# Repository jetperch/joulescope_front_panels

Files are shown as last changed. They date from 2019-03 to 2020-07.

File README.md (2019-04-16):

# Joulescope Front Panels

Welcome to Joulescope™ front panel hardware design project.  This project 
contains the open source hardware designs for a variety of Joulescope front
panels.  These front panels customize Joulescope so that it can more easily 
connect to your power supply and target device.
For more information on Joulescope, see 
[www.joulescope.com](https://www.joulescope.com).

As of Mar 2019, all designs were done in Autodesk Eagle PCB.

The [Baseline PDF](fp_baseline.pdf) show the board outline and critical 
dimensions.

The boards have been fabricated using PCBWay. 
Here are the order notes ([example](pcbway_order.png)):

* Size: 77.6 x 26.6 mm
* Solder Mask: Black
* Surface Finish: HASL lead free, yes to accept ENIG substitution
* Special requests: Place all markings (such as pcb order number) on back.  Add flammability rating marking, such as 94V-0.

## License

All Joulescope front-panel designs are released under the 
permissive Apache 2.0 license.

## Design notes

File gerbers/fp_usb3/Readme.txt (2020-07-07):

Project: JouleScope_USB3

Files are provided "AS IS" for reference only, 
WITHOUT WARRANTY OF ANY KIND, EXPRESS OR IMPLIED.  

Designed by: 
    Mikhail Volkov
    Mettler-Toledo AutoChem, Inc.

As of July 6, 2020, I authorize Jetperch LLC to add these files
to the joulescope_front_panel repository under either the 
Apache 2.0 license or the 
Creative Commons 4.0 Attribution (CC BY) license.

---

Number of copper layers: 4
Layer Stackup:
 L01_TOP - signal
 L02_PLN - gnd
 L03_PLN - 
 L04_PLN - power

Control the single-ended characteristic impedance (Z0) of USB signals to between 40 Ohm and 55 Ohm
Control the differential impedance (Zdiff) of the USB 2.0 DP/DM signals to 90 Ohm, +5/-10 Ohm
Control the differential impedance (Zdiff) of the USB 3.0 (3.1) SS_TX+/- and SS_RX+/- signals to 85 Ohm, +/-5 Ohm

UL:	YES	
Material Thickness:	.062
MatSpec:	NP-175  or equivalent
SMColor:	Black
IDColor (Silk Screen):	White
Finished Copper Weight:1 oz. inners - 1.5 oz. outers
Plating Finish:	Imm. Gold	
Number of copper layers: 4

Micro-vias: None
Buried vias: None, vias throughtout
Via in pad: No
PCB outline and cutouts on: Mechanic, TopPrint, BotPrint, DrillMap
Software used: WinQcad

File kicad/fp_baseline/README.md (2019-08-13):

# Kicad versions of Joulescope front panel 

This is a conversion from the pdf dimensioned drawing of the baseline Joulescope JS110 front panel.

## Main features

* All files were initially generated in Kicad Application Version: (5.1.0)-1, release build
* The board edge, SMD pads, pin3 via, screw holes, light pipe hole are implemented in a .kicad_mod footprint file
* The copper pours are implemented in the .kicad_pcb file, as they will need to be recalculated every time you add or move additional components
* There is a specific .lib kicad symbol included, which may make your schematics easier to read, as opposed to a generic 5 pin header

Initial conversion by @SimonMerrett 
Please submit all pull requests and issues to @mliberty1 but be aware that the Kicad files are a community contribution

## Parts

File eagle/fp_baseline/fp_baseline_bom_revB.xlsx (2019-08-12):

Baseline Front Panel BOM - Rev B
2019 Aug 12
# | Ref Des | Qty | Value | Package | Description | Mfg | Mfg Part # | Notes
1 | J1 | 1 |  | 0.1" 1x5 SM | Surface mount header | Samtec | TSM-105-01-S-SV
2 | H1 | 1 |  |  | Light pipe | Dialight | 51513020125F
3 | PCB | 1 |  |  | PCB

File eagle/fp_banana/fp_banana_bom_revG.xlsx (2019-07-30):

Banana Jack Front Panel BOM - Rev G
2019 June 10
# | Ref Des | Qty | Value | Package | Description | Mfg | Mfg Part # | Notes
1 | J1, J3 | 2 |  |  | Safety banana jack - black | Cal Test | CT3149-0
2 | J2, J4 | 2 |  |  | Safety banana jack - red | Cal Test | CT3149-2
3 | J5 | 1 |  | 0.1" 1x5 SM | Surface mount header | Samtec | TSM-105-01-S-SV
4 | H1 | 1 |  |  | Light pipe | Dialight | 51513020125F
5 |  | 1 |  |  | PCB | PCBWay | W40090AXN58

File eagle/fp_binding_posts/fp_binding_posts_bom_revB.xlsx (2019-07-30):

Binding Post Front Panel BOM - rev B
2019 June 10
# | Ref Des | Qty | Package | Description | Mfg | Mfg Part # | Notes
1 | J2, J4 | 2 |  | Binding post - red | Cinch | 111-0702-001
2 | J1, J3 | 2 |  | Binding post - black | Cinch | 111-0703-001
3 | J5 | 1 | 0.1" 1x5 SM | Surface mount header | Samtec | TSM-105-01-S-SV
4 | H1 | 1 |  | Light pipe | Dialight | 51513020125F

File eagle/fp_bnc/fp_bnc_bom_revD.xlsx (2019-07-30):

BNC Front Panel BOM - revD
2019 June 10
# | Ref Des | Qty | Value | Package | Description | Mfg | Mfg Part # | Notes
1 | J1, J2 | 2 |  |  | BNC connector | Amphenol | 031-5329-52RFX
2 | J5 | 1 |  |  | Surface mount header | Samtec | TSM-110-01-S-SV
3 | H1 | 1 |  |  | Light Pipe | Dialight | 51513020125F

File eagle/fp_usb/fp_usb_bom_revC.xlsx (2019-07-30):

USB Front Panel BOM - rev C
2019 June 10
# | Ref Des | Qty | Value | Package | Description | Mfg | Mfg Part # | Notes
1 | J5 | 1 |  | 0.1" 1x5 SM | Surface mount header | Samtec | TSM-105-01-S-SV
2 | J3 | 1 |  |  | USB B connector | Samtec | USB-B-S-F-B-TH
3 | J4 | 1 |  |  | USB A connector | Amphenol | 87583-3010RPALF
4 | H1 | 1 |  |  | Light Pipe | Dialight | 51513020125F

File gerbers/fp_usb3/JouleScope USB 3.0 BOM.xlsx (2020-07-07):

QTY | Product/Value | Package | Reference Designators | Manufacturer | PN | Mouser PN
1 | HEADER_5 | CON-HDR::TSM-105-01-S-SV | J1 | Samtec | TSM-105-01-S-SV | 200-TSM10501SSV
1 | USB_3.0_A | CON-HDR::USB_3.0_A | J3 | Amphenol FCI | 10117836-001LF | 649-10117836-001LF
1 | USB_3.0_MICRO-B | CON-HDR::MM_USB3+MICRO-B_vertical | J2 | Mill-Max | 897-10-010-00-300002 | 575-8971001000300002
2 | * | 1PIN::3_56mm_mounting | m1-m2
1 | * | 1PIN::110/100 | m3

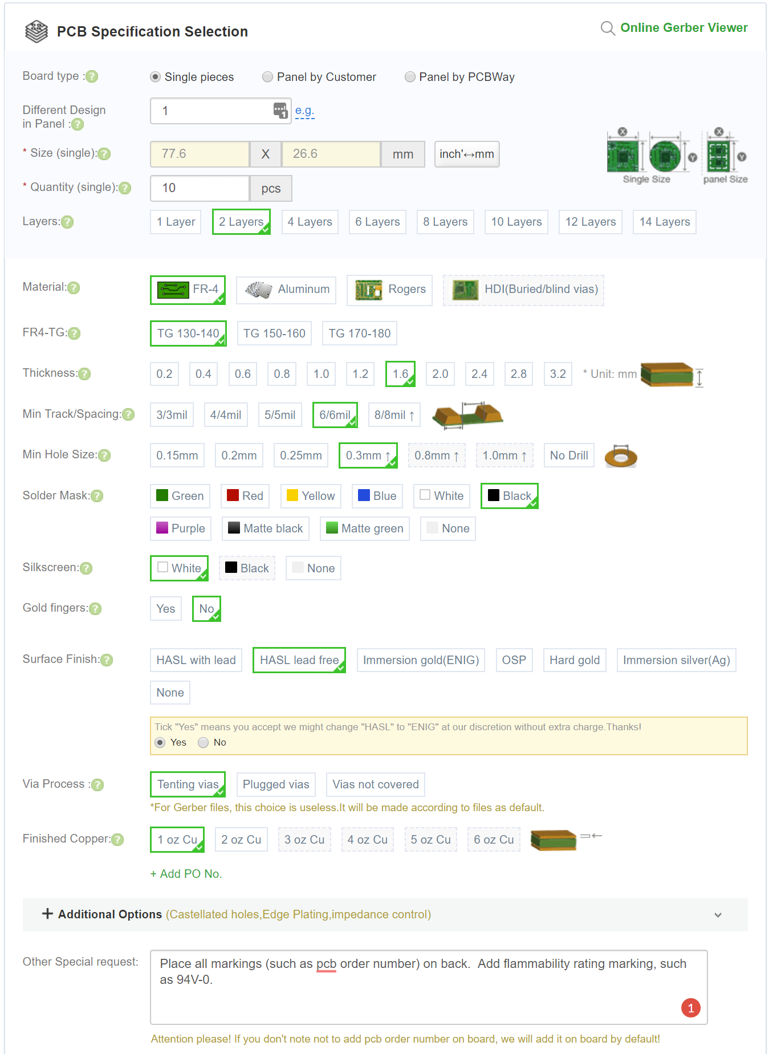
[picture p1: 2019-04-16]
pcbway_order.png

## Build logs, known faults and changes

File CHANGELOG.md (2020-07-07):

# CHANGELOG

This file contains the list of changes made to joulescope_front_panels.

## 0.2.3

2020 Jul 7

* Added fp_usb3 gerber design.  Thank you Mettler-Toledo AutoChem!

## 0.2.2

2019 Oct 21

* Fixed binding post centerline offset dimension.

## 0.2.1

2019 May 9

* Modified USB back panel to move GPI/O cutout.
* Fixed USB back panel file naming.

## 0.2.0

2019 Apr 16

* Increased clearances from chassis/enclosure ground.
* Improved text.
* Added gerbers.
* Added USB back panel.
* Added PCBWay order notes to readme.

## 0.1.0

2019 Jan 25

*   Initial public release.

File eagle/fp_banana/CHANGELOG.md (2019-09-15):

# Joulescope banana front panel PCB

## Version H

2019 Sep 15

* Increased 5x1 connector pad width from 45 mil to 50 mil.
* Added brief fab notes & fab drawing.
* Improved dimensioning for clarity.
* Removed excessive number of EXT_NEG vias.

## Version G

2019 Apr 16

* Removed copper for chassis/enclosure ground clearance
* Added word "isolated"

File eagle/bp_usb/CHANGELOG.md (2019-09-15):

# Joulescope USB back panel PCB

## Version J

2019 Sep 15

* Added brief fab notes.

## Version H

2019 May 9

* Moved GPI/O cutout.
* Fixed schematic name.

## Version G

2019 Apr 16

* Improved location hole locations, +0.5 mm
* Added text detail

## Version E

2019 March 17

* Added GPI/O feature

## Version D

* ??

## Version C

2018 September 4

*   Moved LED to main board.  Added light pipe.

## Version C

2018 September 4

*   Moved LED to main board.  Added light pipe.

## Revision B

2018 July 9

*   Fix incorrect Joulescope board center: move USB hole and connector
*   Swap connector pins - incorrect polarity, +5V towards outside.

## Revision A

2018 June 1

*  Initial version

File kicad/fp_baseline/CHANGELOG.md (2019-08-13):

# Joulescope baseline - starting example

## Version B - 20190813

2019 Aug 13

* Initial commit of Kicad files.

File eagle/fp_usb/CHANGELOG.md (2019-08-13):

# Joulescope USB front panel PCB

## Version D

2019 Aug 13

* Fixed mounting hole location which was off by 0.18 mm (7 mil).

## Version C

2019 Apr 16

* Removed copper for chassis/enclosure ground clearance
* Added input text: "isolated, 0-15V, 0-3A"
* Removed ground pour between D_P & D_N near "OUT".

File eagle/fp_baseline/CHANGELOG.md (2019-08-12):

# Joulescope baseline - starting example

## Version B - 20190812

2019 Aug 12

* Added gerbers
* Added BOM
* Added "Rev B" text to brd file.

## Version B - 20190730

2019 Jul 30

* Added part numbers.
* Renumbered parts for clarity.
* Added keepout info and dimensions.
* Added lightpipe drill size.

## Version A - 20190406

2019 Apr 16

* Removed copper for chassis/enclosure ground clearance
* Added word "isolated"

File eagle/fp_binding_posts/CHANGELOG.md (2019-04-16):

# Joulescope BNC front panel PCB

## Version B

2019 Apr 16

* Removed copper for chassis/enclosure ground clearance
* Added word "isolated"

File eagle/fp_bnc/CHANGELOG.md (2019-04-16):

# Joulescope BNC front panel PCB

## Version D

2019 Apr 16

* Removed copper for chassis/enclosure ground clearance
* Added word "isolated"

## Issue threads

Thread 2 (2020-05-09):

Joulescope v2 with embedded logical analyser.

rsglobal, 2020-05-09:
Hello guys,

Thank you for this nice tool.
As a user I may want to put some labels to the graph to match power consumption to some software events.
Usual way to do this is to use some MCU output pin and connect it to the scope together with measuring signal.

In case you like this idea, consider starting another Kickstarter campaign.

Regards.

mliberty1, 2020-05-09:
Hi @rsglobal and thank you for the feedback.

You may be able to do this today using the two general-purpose inputs located next to the host USB port.  Here is an example showing a GPIO event and a related current :
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

The two GPIOs are USB ground referenced, so you may need additional external isolators if your target system is not earth ground referenced.

Does this do what you need?  If not, could you add more detail so that I can better understand how I could make Joulescope better for you?

rsglobal, 2020-05-09:
Ah, that's great. I've missed those pins on the device photo and project homepage.

Thank you for your fast response.

Closed 2020-05-09.

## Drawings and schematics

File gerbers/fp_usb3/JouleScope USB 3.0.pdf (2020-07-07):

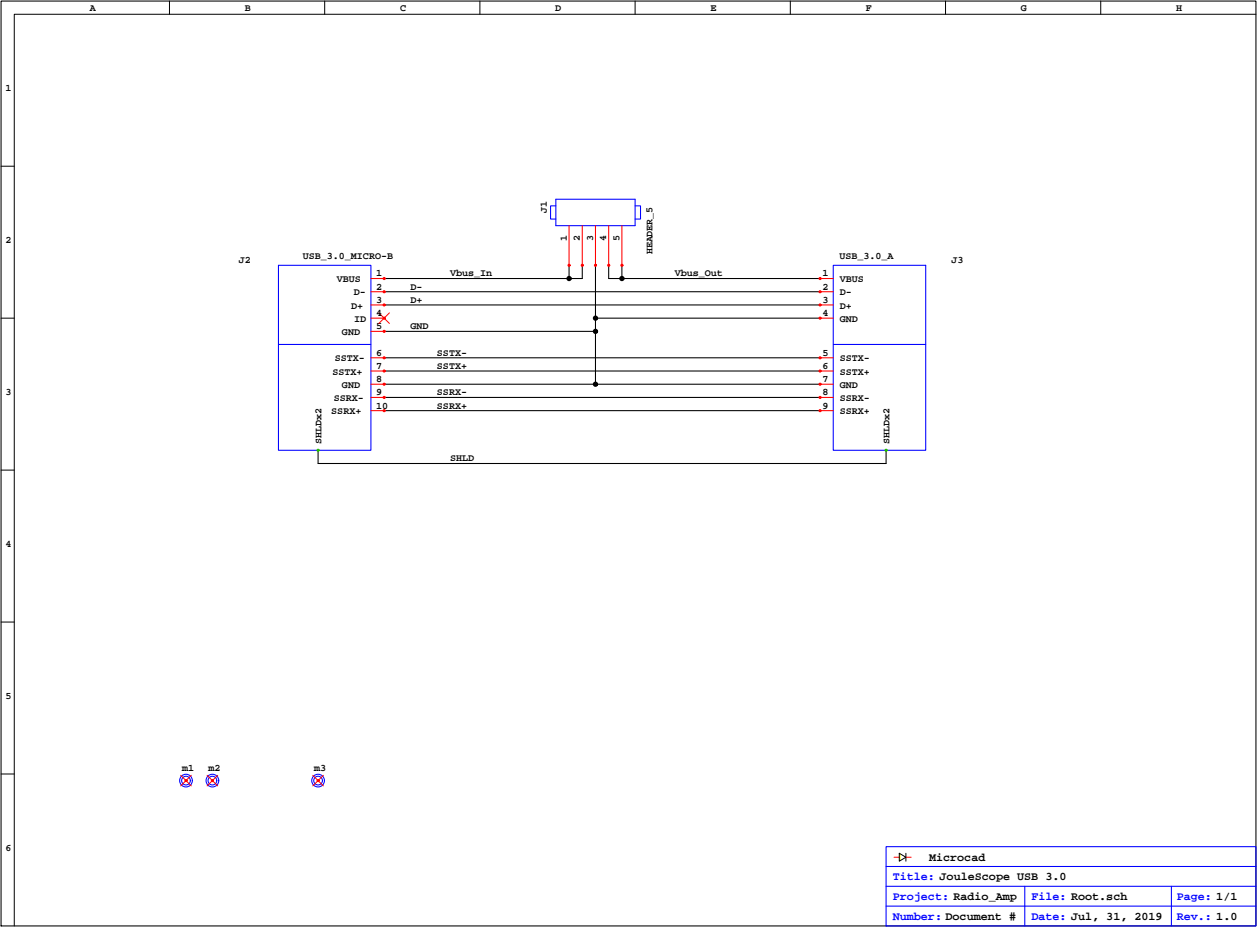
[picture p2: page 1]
SHLD; SSRX+; SSRX-; SSTX+; SSTX-; GND; Vbus_In; Vbus_Out; Number: Document #; Rev.: 1.0; Project:; File: Root.sch; Radio_Amp; Page: 1/1; Date: Jul, 31, 2019; USB_3.0_A; VBUS; SHLDx2; USB_3.0_MICRO-B J2; 10 SSRX+; VBUS SHLDx2; HEADER_5J1

Microcad
Title: JouleScope USB 3.0

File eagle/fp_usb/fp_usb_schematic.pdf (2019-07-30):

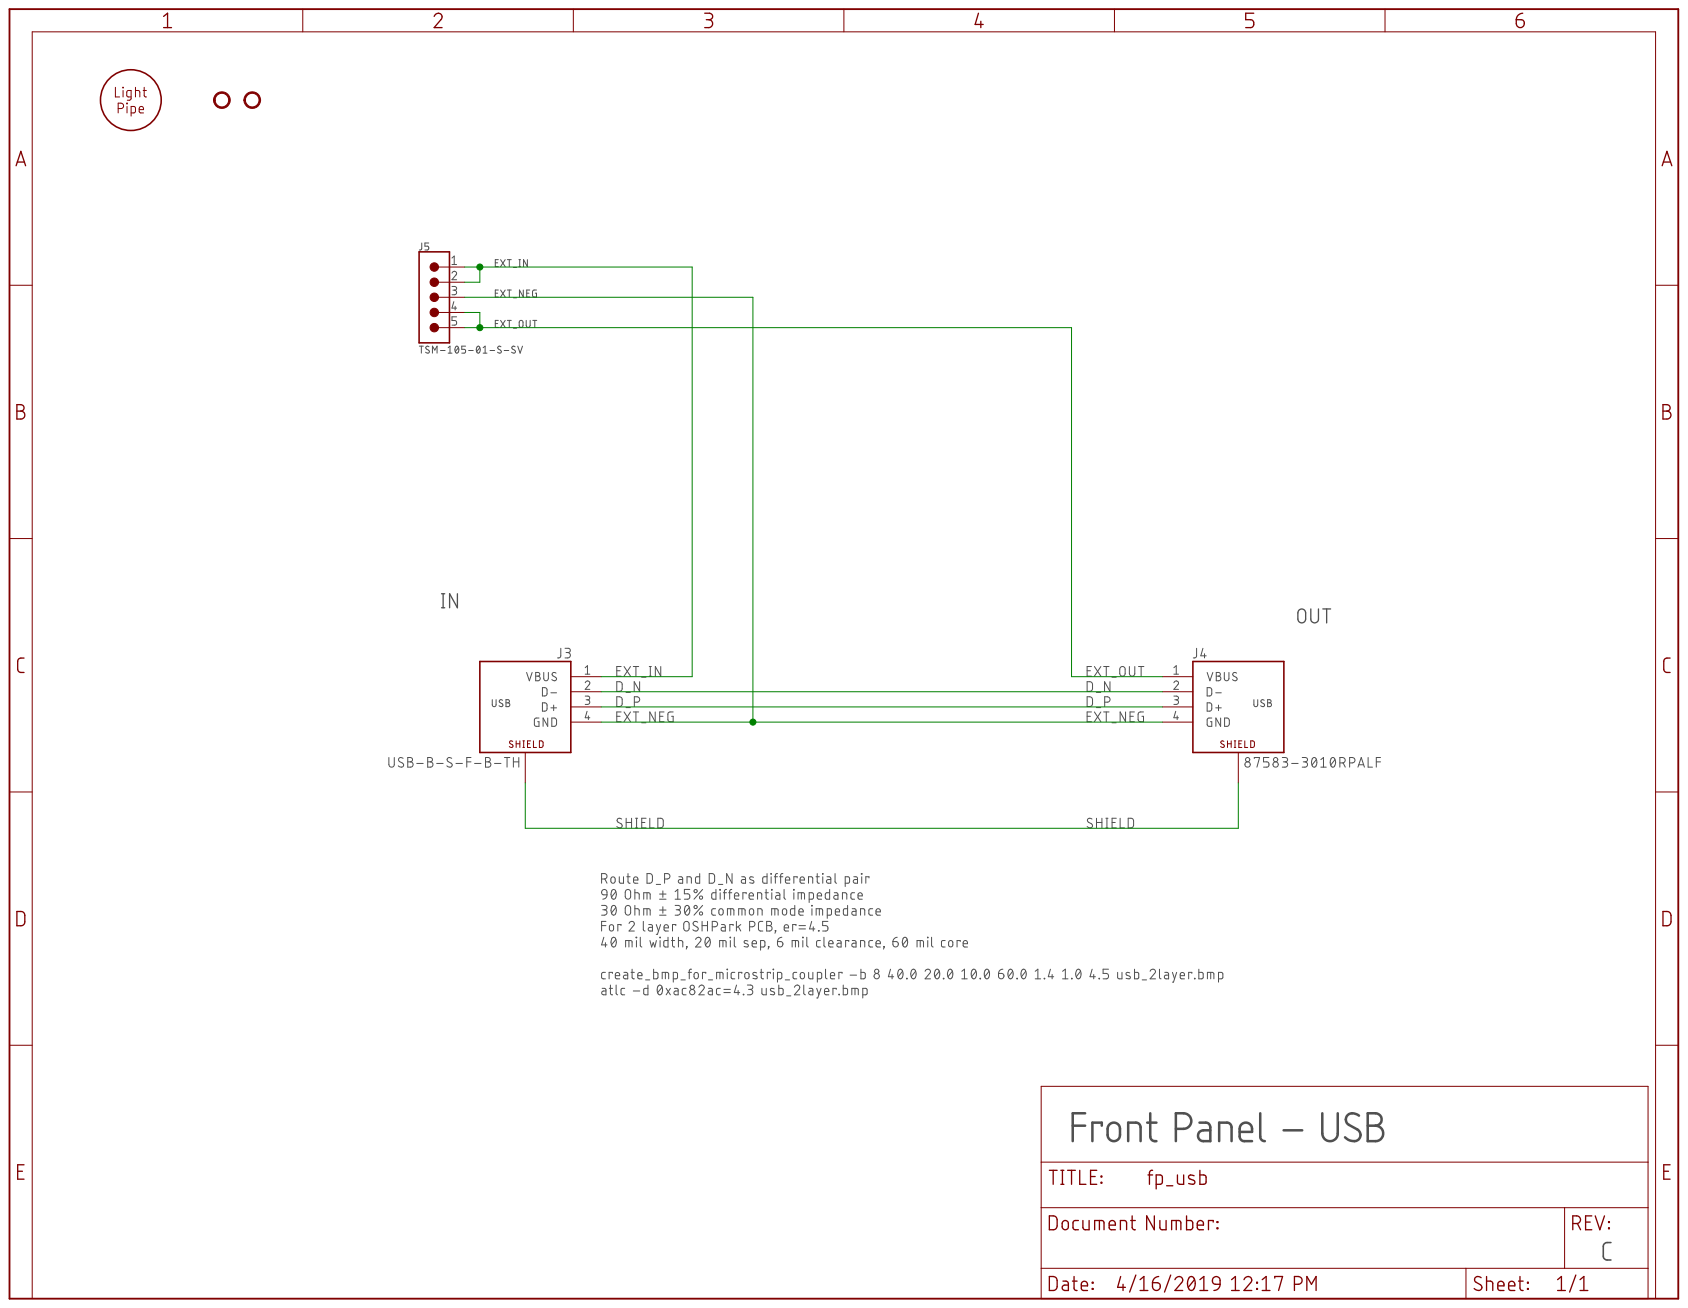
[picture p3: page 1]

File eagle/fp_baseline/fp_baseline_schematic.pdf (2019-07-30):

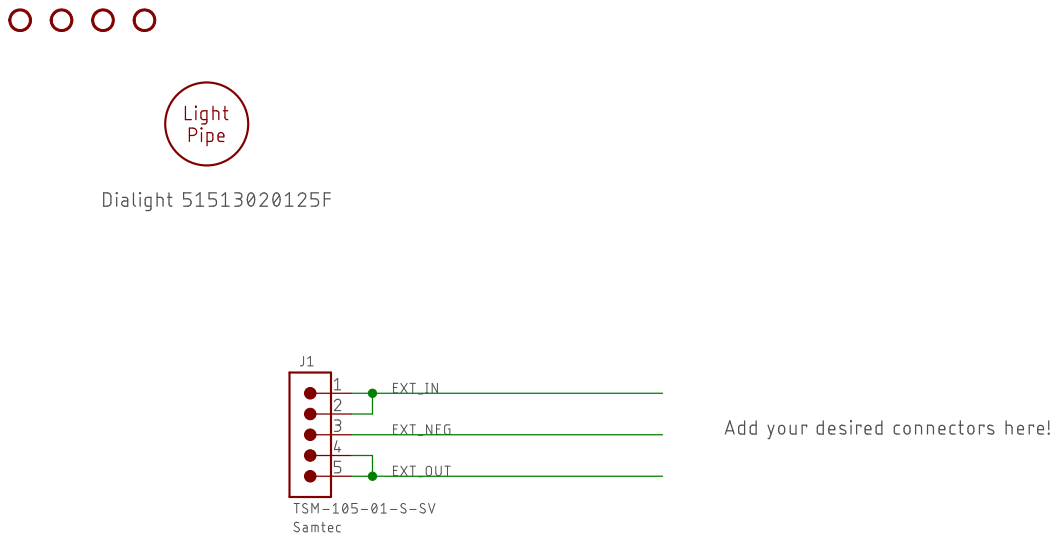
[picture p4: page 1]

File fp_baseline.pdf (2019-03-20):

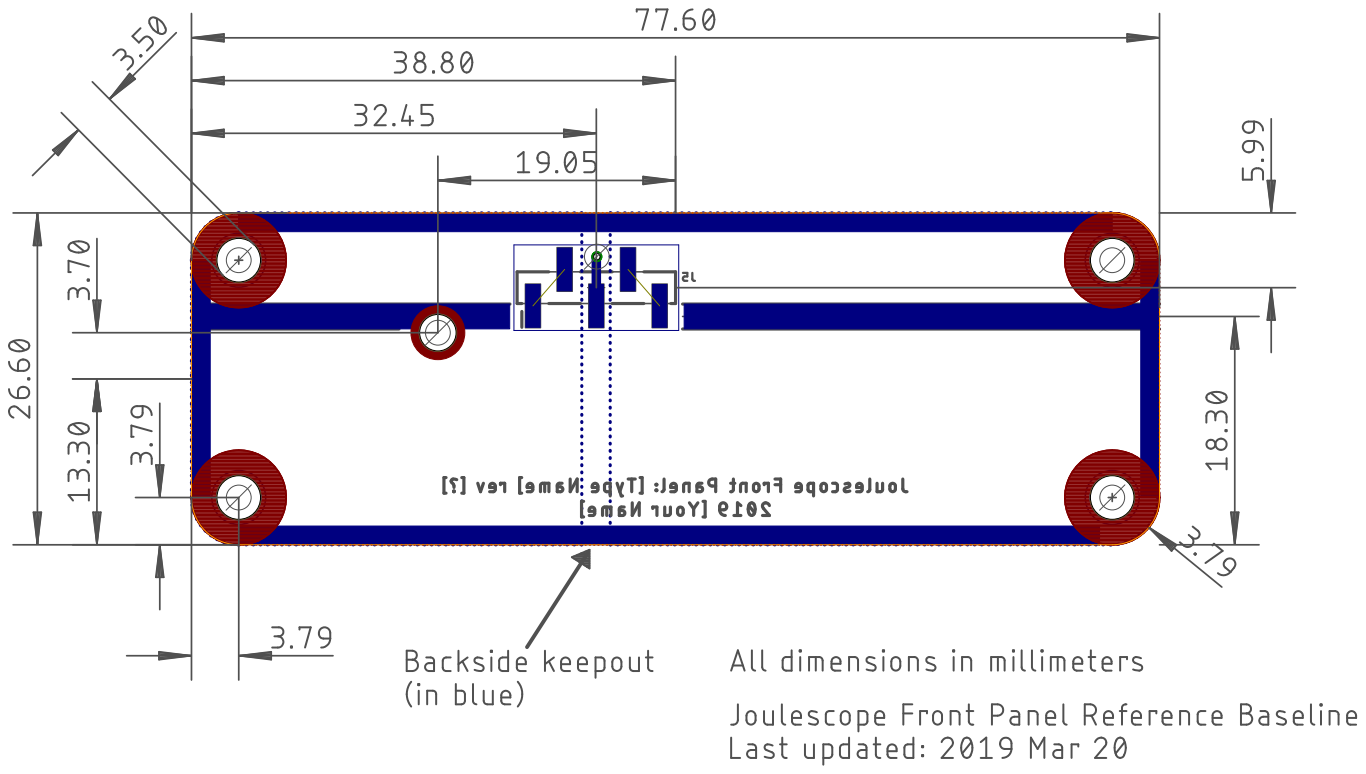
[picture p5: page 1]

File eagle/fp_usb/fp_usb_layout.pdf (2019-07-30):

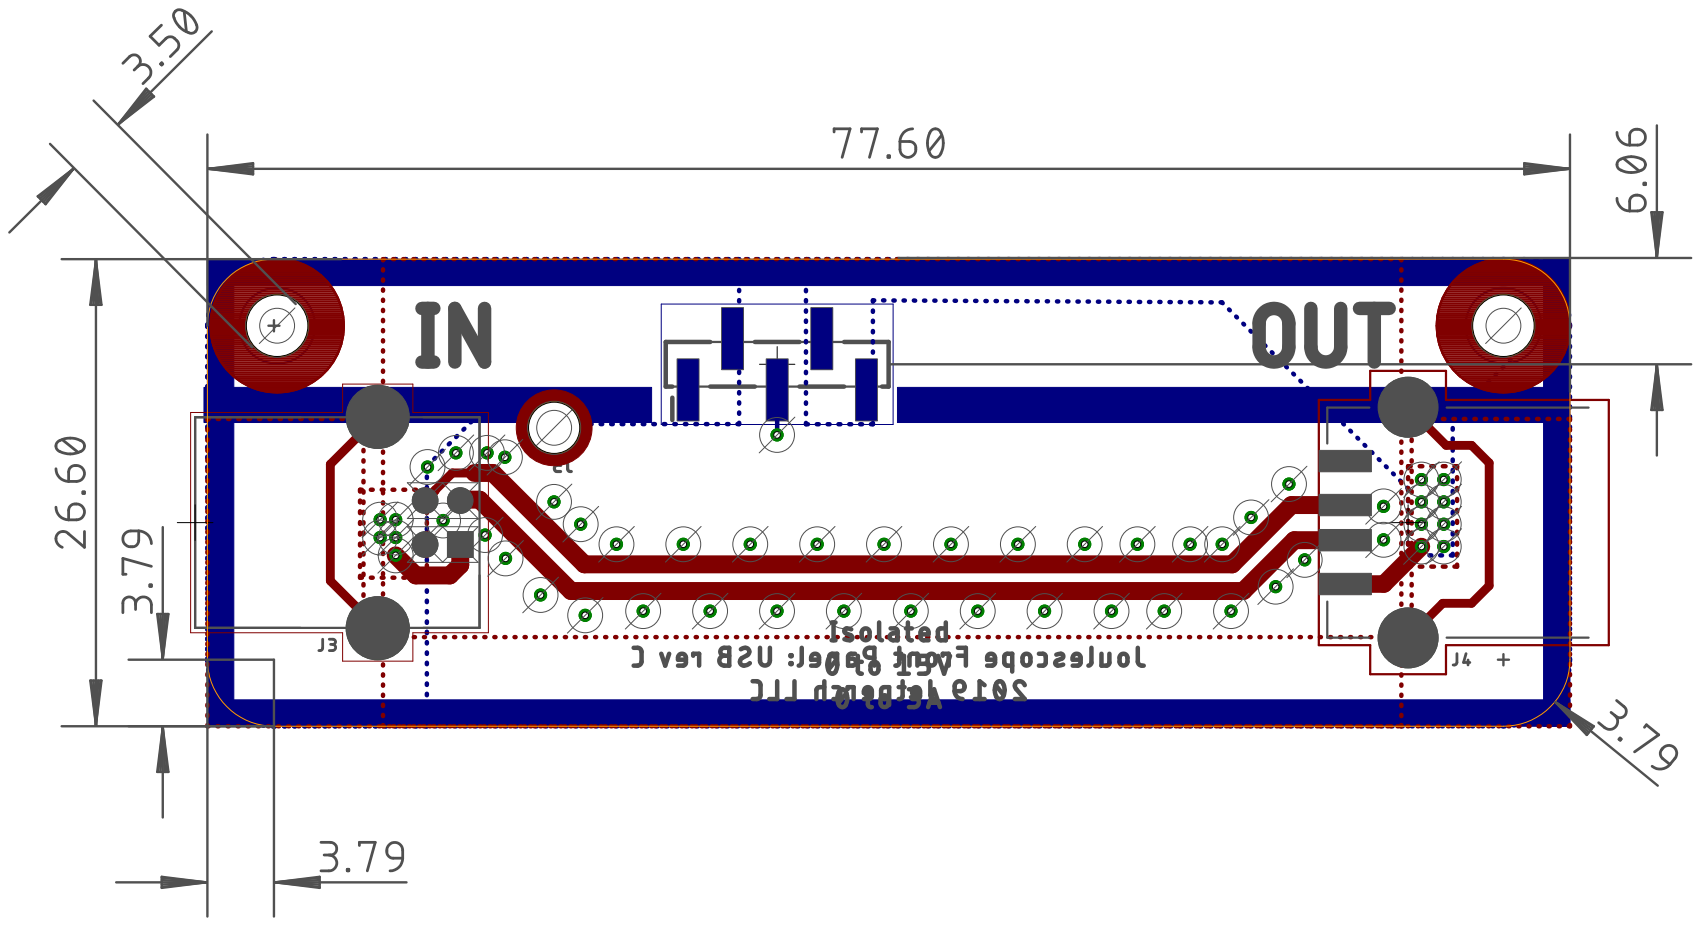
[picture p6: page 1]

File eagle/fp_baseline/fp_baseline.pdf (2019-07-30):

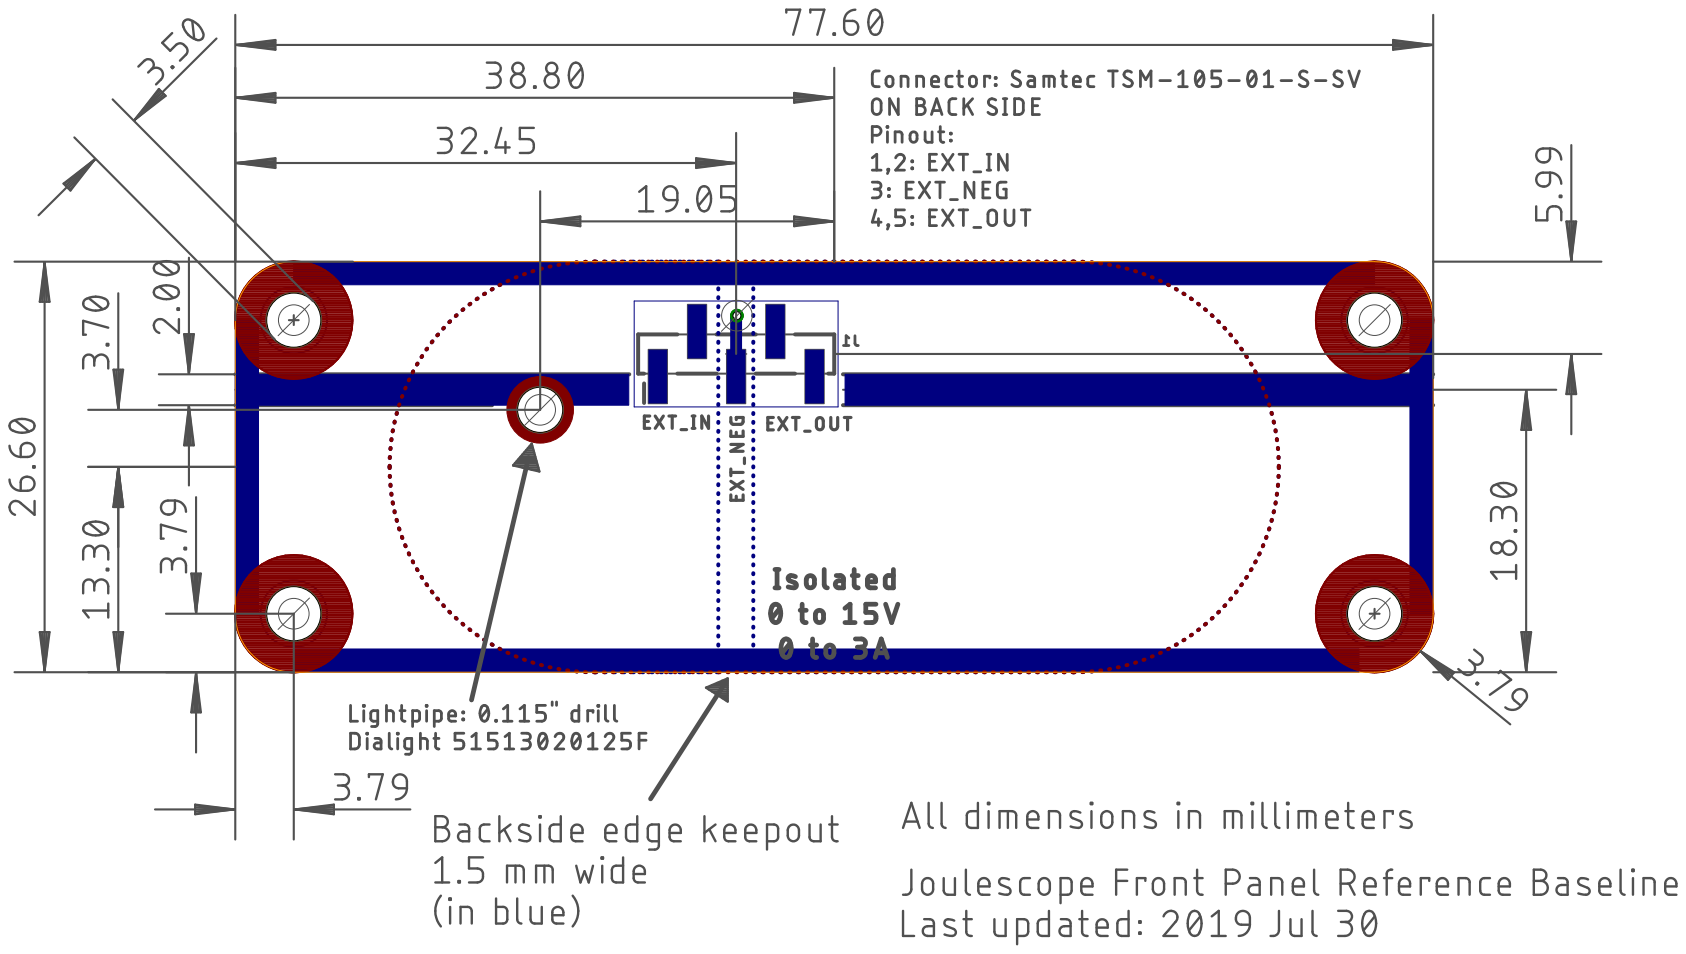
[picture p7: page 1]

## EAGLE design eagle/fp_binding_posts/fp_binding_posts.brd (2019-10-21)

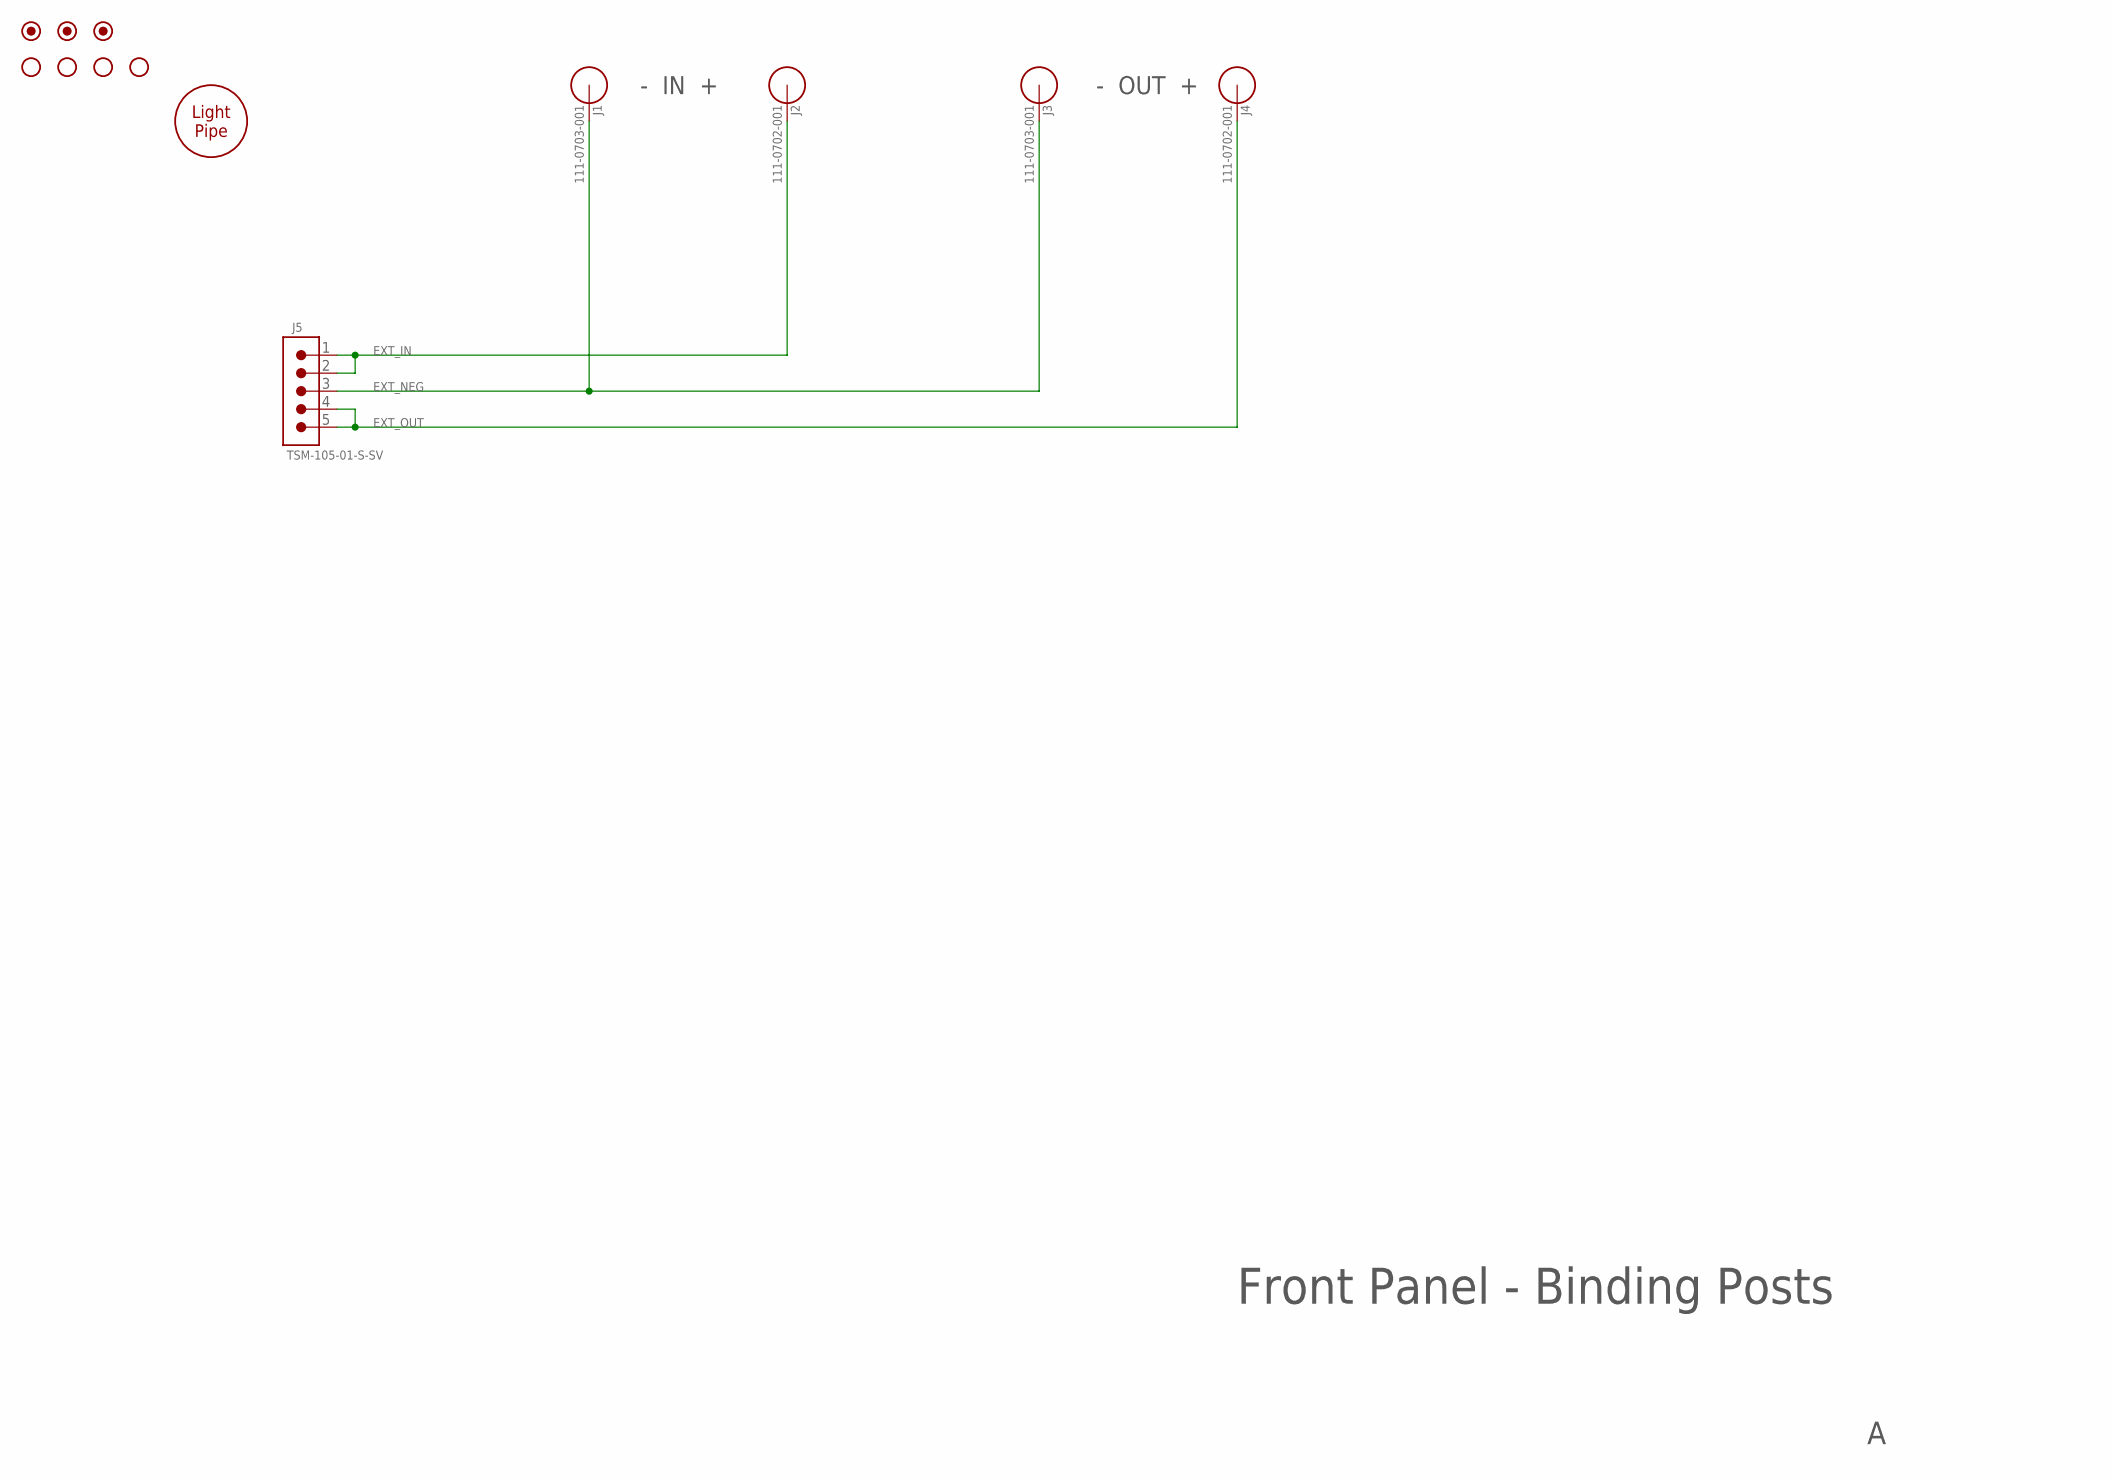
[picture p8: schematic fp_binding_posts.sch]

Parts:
FUD1, FUD2, FUD3: FIDUCIAL_1MM; FIDUCIAL_1MM_2MM
H1: 51513020125F; LP_3MM; MPN 51513020125F
H2, H3, H4, H5: HOLE_#6; HOLE_3.5MM
J1, J3: 111-0703-001; BINDING_POST_6
J2, J4: 111-0702-001; BINDING_POST_6
J5: TSM-105-01-S-SV; CONN_0.1_5X1_MS; MPN TSM-105-01-S-SV

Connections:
EXT_IN: J2.1, J5.1, J5.2
EXT_NEG: J1.1, J3.1, J5.3
EXT_OUT: J4.1, J5.4, J5.5

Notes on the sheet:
Front Panel - Binding Posts
- IN +
- OUT +

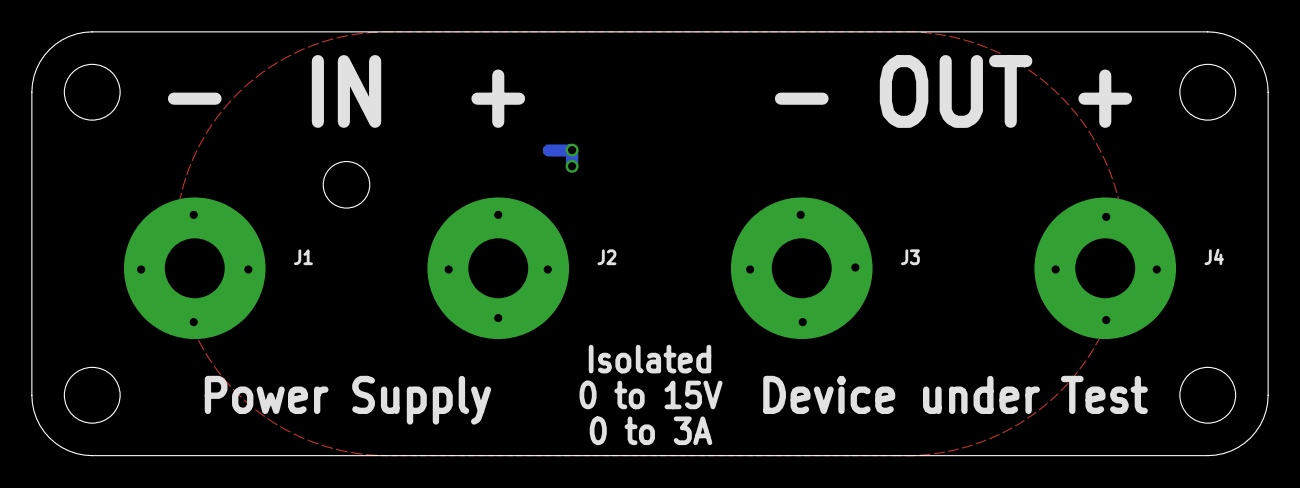
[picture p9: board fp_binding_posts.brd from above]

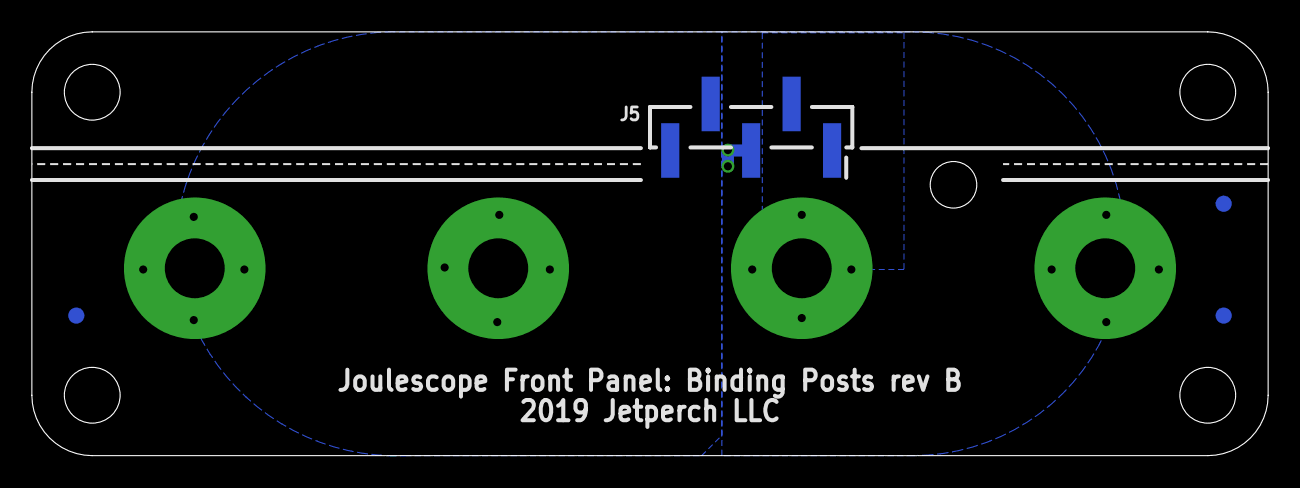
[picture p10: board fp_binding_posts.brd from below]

Board: 2 copper layers, 77.6 x 26.6 mm, 13 parts (4 on the bottom side), 3 nets.

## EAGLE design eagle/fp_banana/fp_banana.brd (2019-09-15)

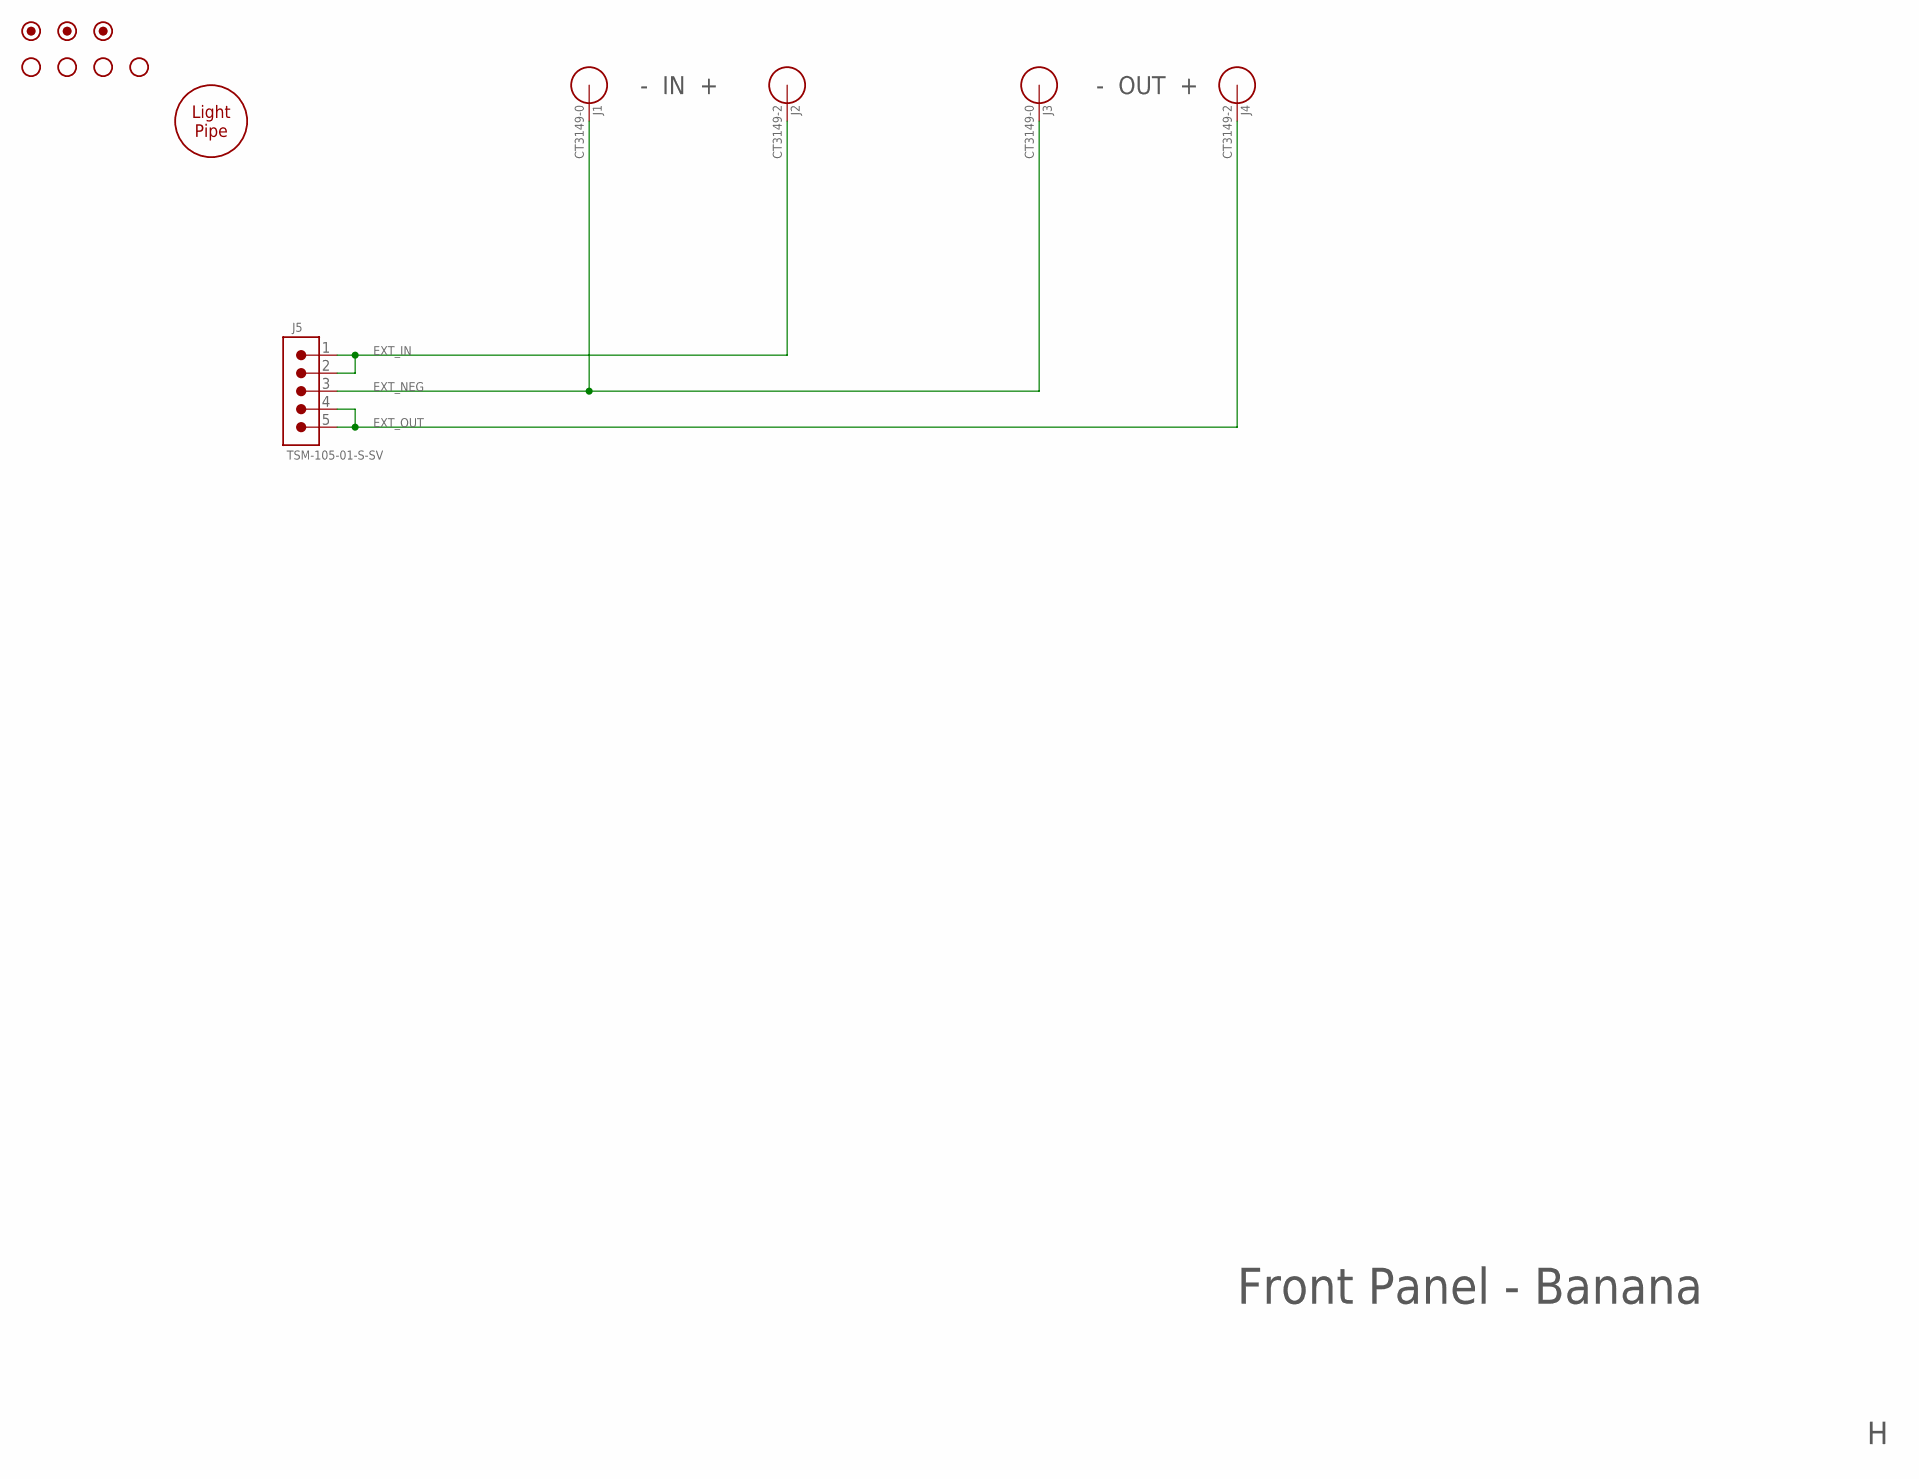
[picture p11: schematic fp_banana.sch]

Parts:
FUD1, FUD2, FUD3: FIDUCIAL_1MM; FIDUCIAL_1MM_2MM
H1: 51513020125F; LP_3MM; MPN 51513020125F
H2, H3, H4, H5: HOLE_#6; HOLE_3.5MM
J1, J3: CT3149-0; CT3149
J2, J4: CT3149-2; CT3149
J5: TSM-105-01-S-SV; CONN_0.1_5X1_MS; MPN TSM-105-01-S-SV

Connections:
EXT_IN: J2.A, J5.1, J5.2
EXT_NEG: J1.A, J3.A, J5.3
EXT_OUT: J4.A, J5.4, J5.5

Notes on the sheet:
Front Panel - Banana
- IN +
- OUT +

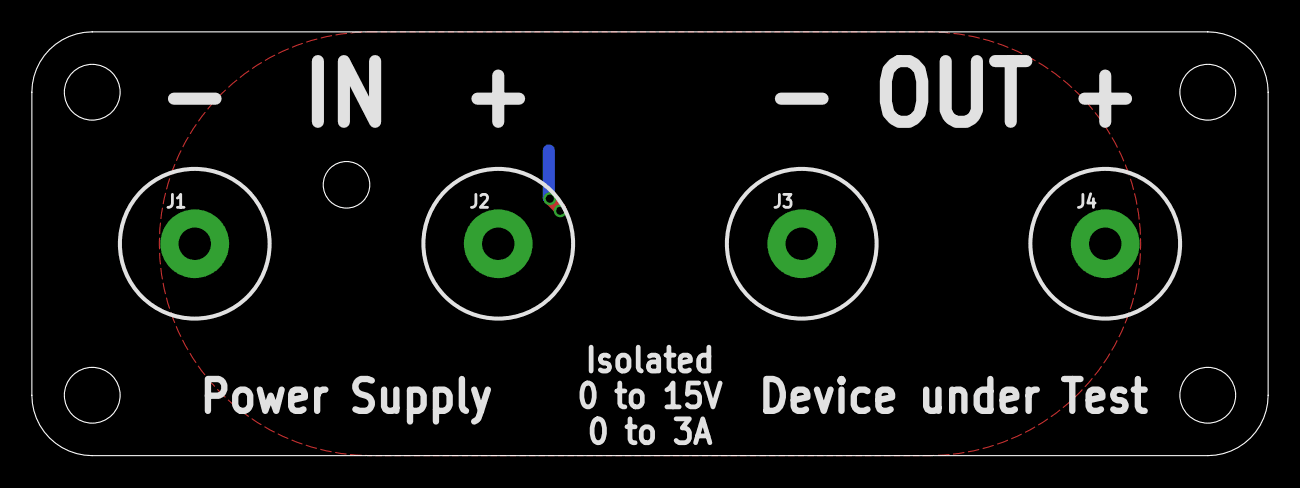
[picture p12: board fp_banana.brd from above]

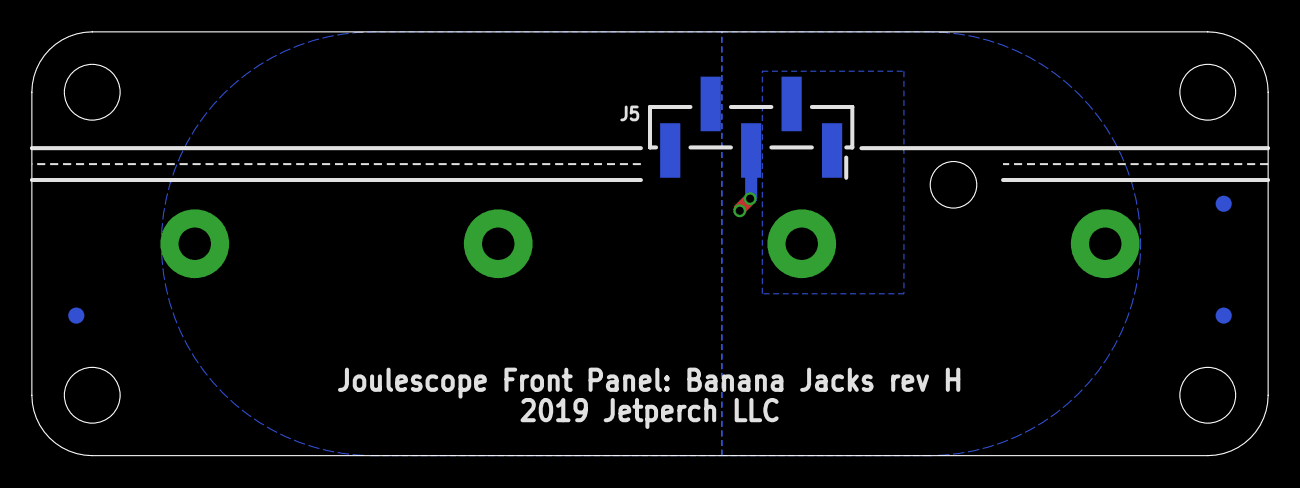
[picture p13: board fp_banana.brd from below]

Board: 2 copper layers, 77.6 x 26.6 mm, 13 parts (4 on the bottom side), 3 nets.

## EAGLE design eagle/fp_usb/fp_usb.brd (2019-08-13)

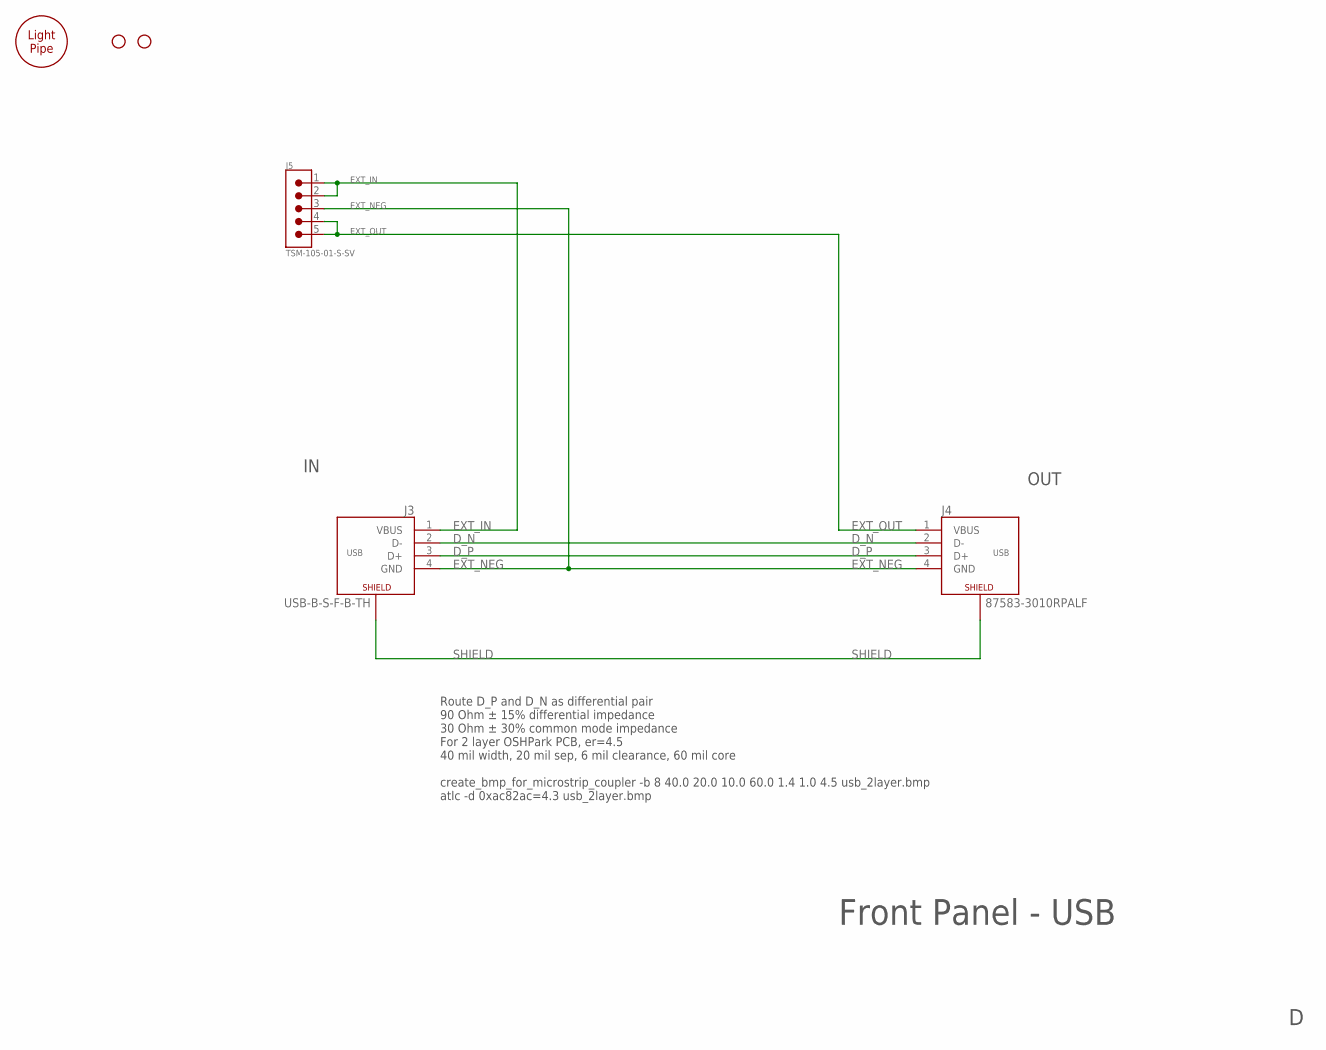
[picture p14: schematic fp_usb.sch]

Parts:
H1: 51513020125F; LP_3MM; MPN 51513020125F
H3, H4: HOLE_#6; HOLE_3.5MM
J3: USB-B-S-F-B-TH; USB-B-TH; MPN USB-B-S-F-B-TH
J4: 87583-3010RPALF; USB-A_RPCT; MPN 87583-3010RPALF
J5: TSM-105-01-S-SV; CONN_0.1_5X1_MS; MPN TSM-105-01-S-SV

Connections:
D_N: J3.2 (D-), J4.2 (D-)
D_P: J3.3 (D+), J4.3 (D+)
EXT_IN: J3.1 (VBUS), J5.1, J5.2
EXT_NEG: J3.4 (GND), J4.4 (GND), J5.3
EXT_OUT: J4.1 (VBUS), J5.4, J5.5
SHIELD: J3.SHIELD@1 (SHIELD), J3.SHIELD@2 (SHIELD), J4.SHIELD@1 (SHIELD), J4.SHIELD@2 (SHIELD)

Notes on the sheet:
Front Panel - USB
OUT
Route D_P and D_N as differential pair 90 Ohm ± 15% differential impedance 30 Ohm ± 30% common mode impedance For 2 layer OSHPark PCB, er=4.5 40 mil width, 20 mil sep, 6 mil clearance, 60 mil core create_bmp_for_microstrip_coupler -b 8 40.0 20.0 10.0 60.0 1.4 1.0 4.5 usb_2layer.bmp atlc -d 0xac82ac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

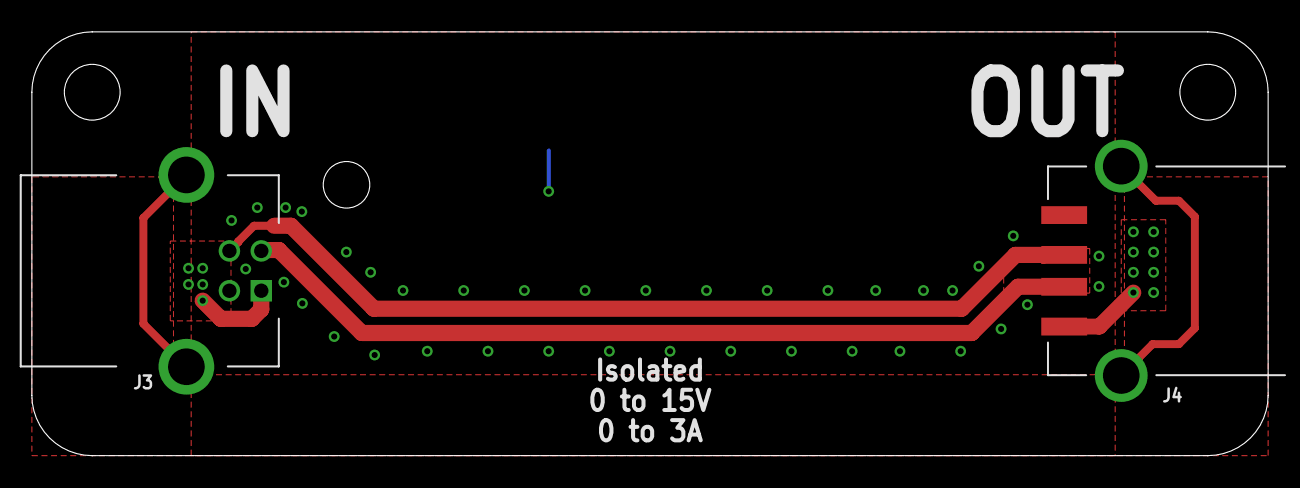
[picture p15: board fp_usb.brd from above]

Board: 2 copper layers, 77.6 x 26.6 mm, 6 parts (1 on the bottom side), 6 nets.

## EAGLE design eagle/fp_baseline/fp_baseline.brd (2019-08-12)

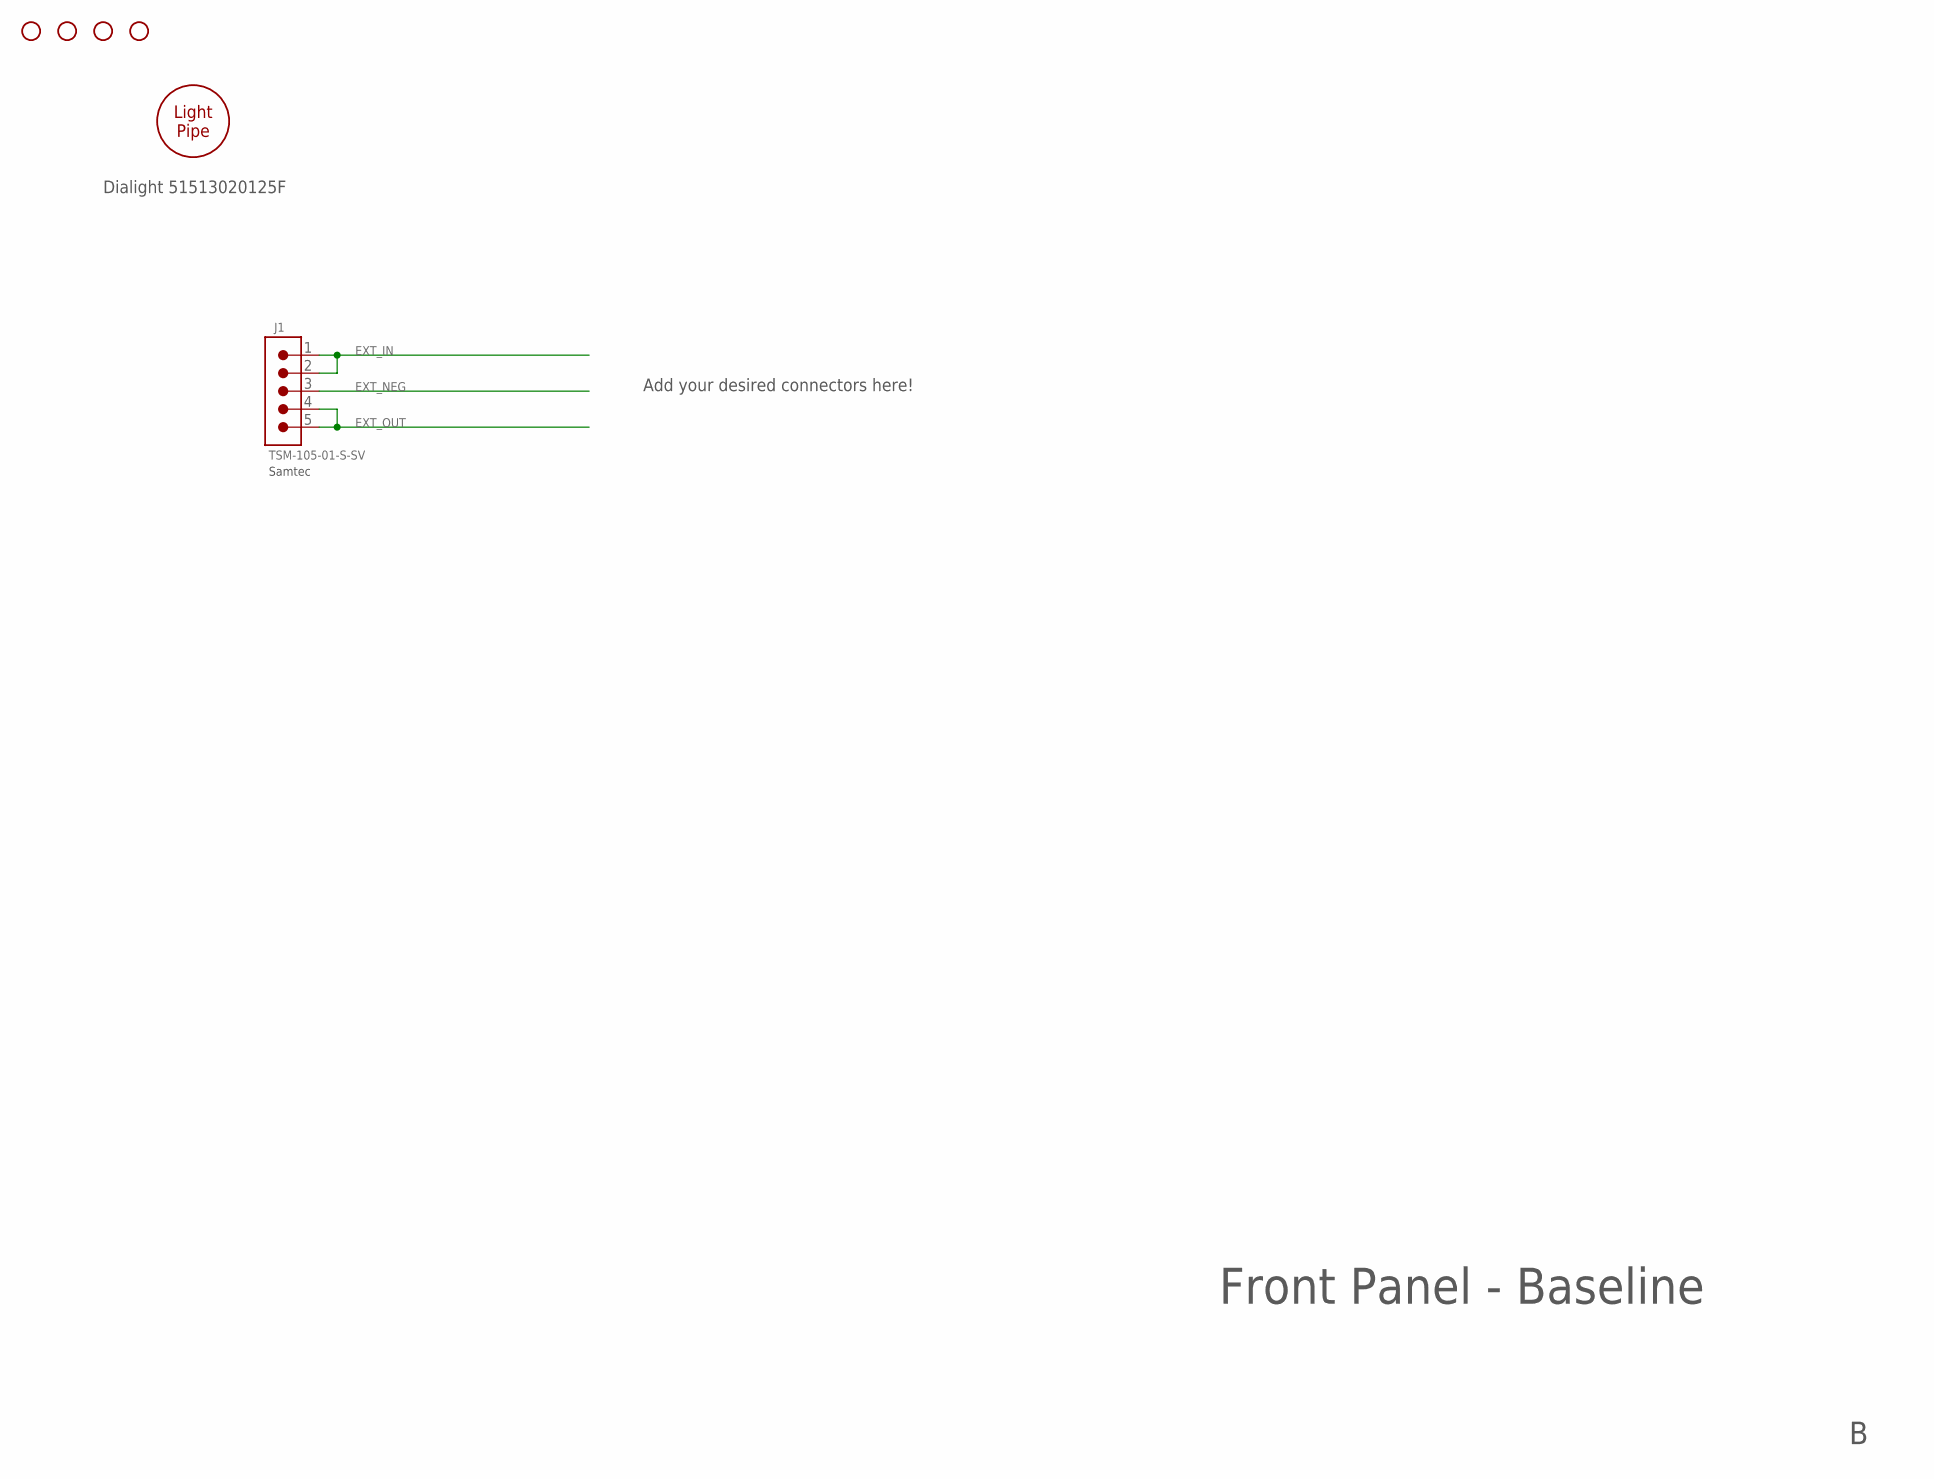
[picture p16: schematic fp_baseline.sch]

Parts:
H1: 51513020125F; LP_3MM; MPN 51513020125F
H2, H3, H4, H5: HOLE_#6; HOLE_3.5MM
J1: TSM-105-01-S-SV; CONN_0.1_5X1_MS; MPN TSM-105-01-S-SV

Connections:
EXT_IN: J1.1, J1.2
EXT_NEG: J1.3
EXT_OUT: J1.4, J1.5

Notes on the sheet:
Front Panel - Baseline
Add your desired connectors here!
Dialight 51513020125F
Samtec

Board: 2 copper layers, 6 parts (1 on the bottom side), 2 nets.

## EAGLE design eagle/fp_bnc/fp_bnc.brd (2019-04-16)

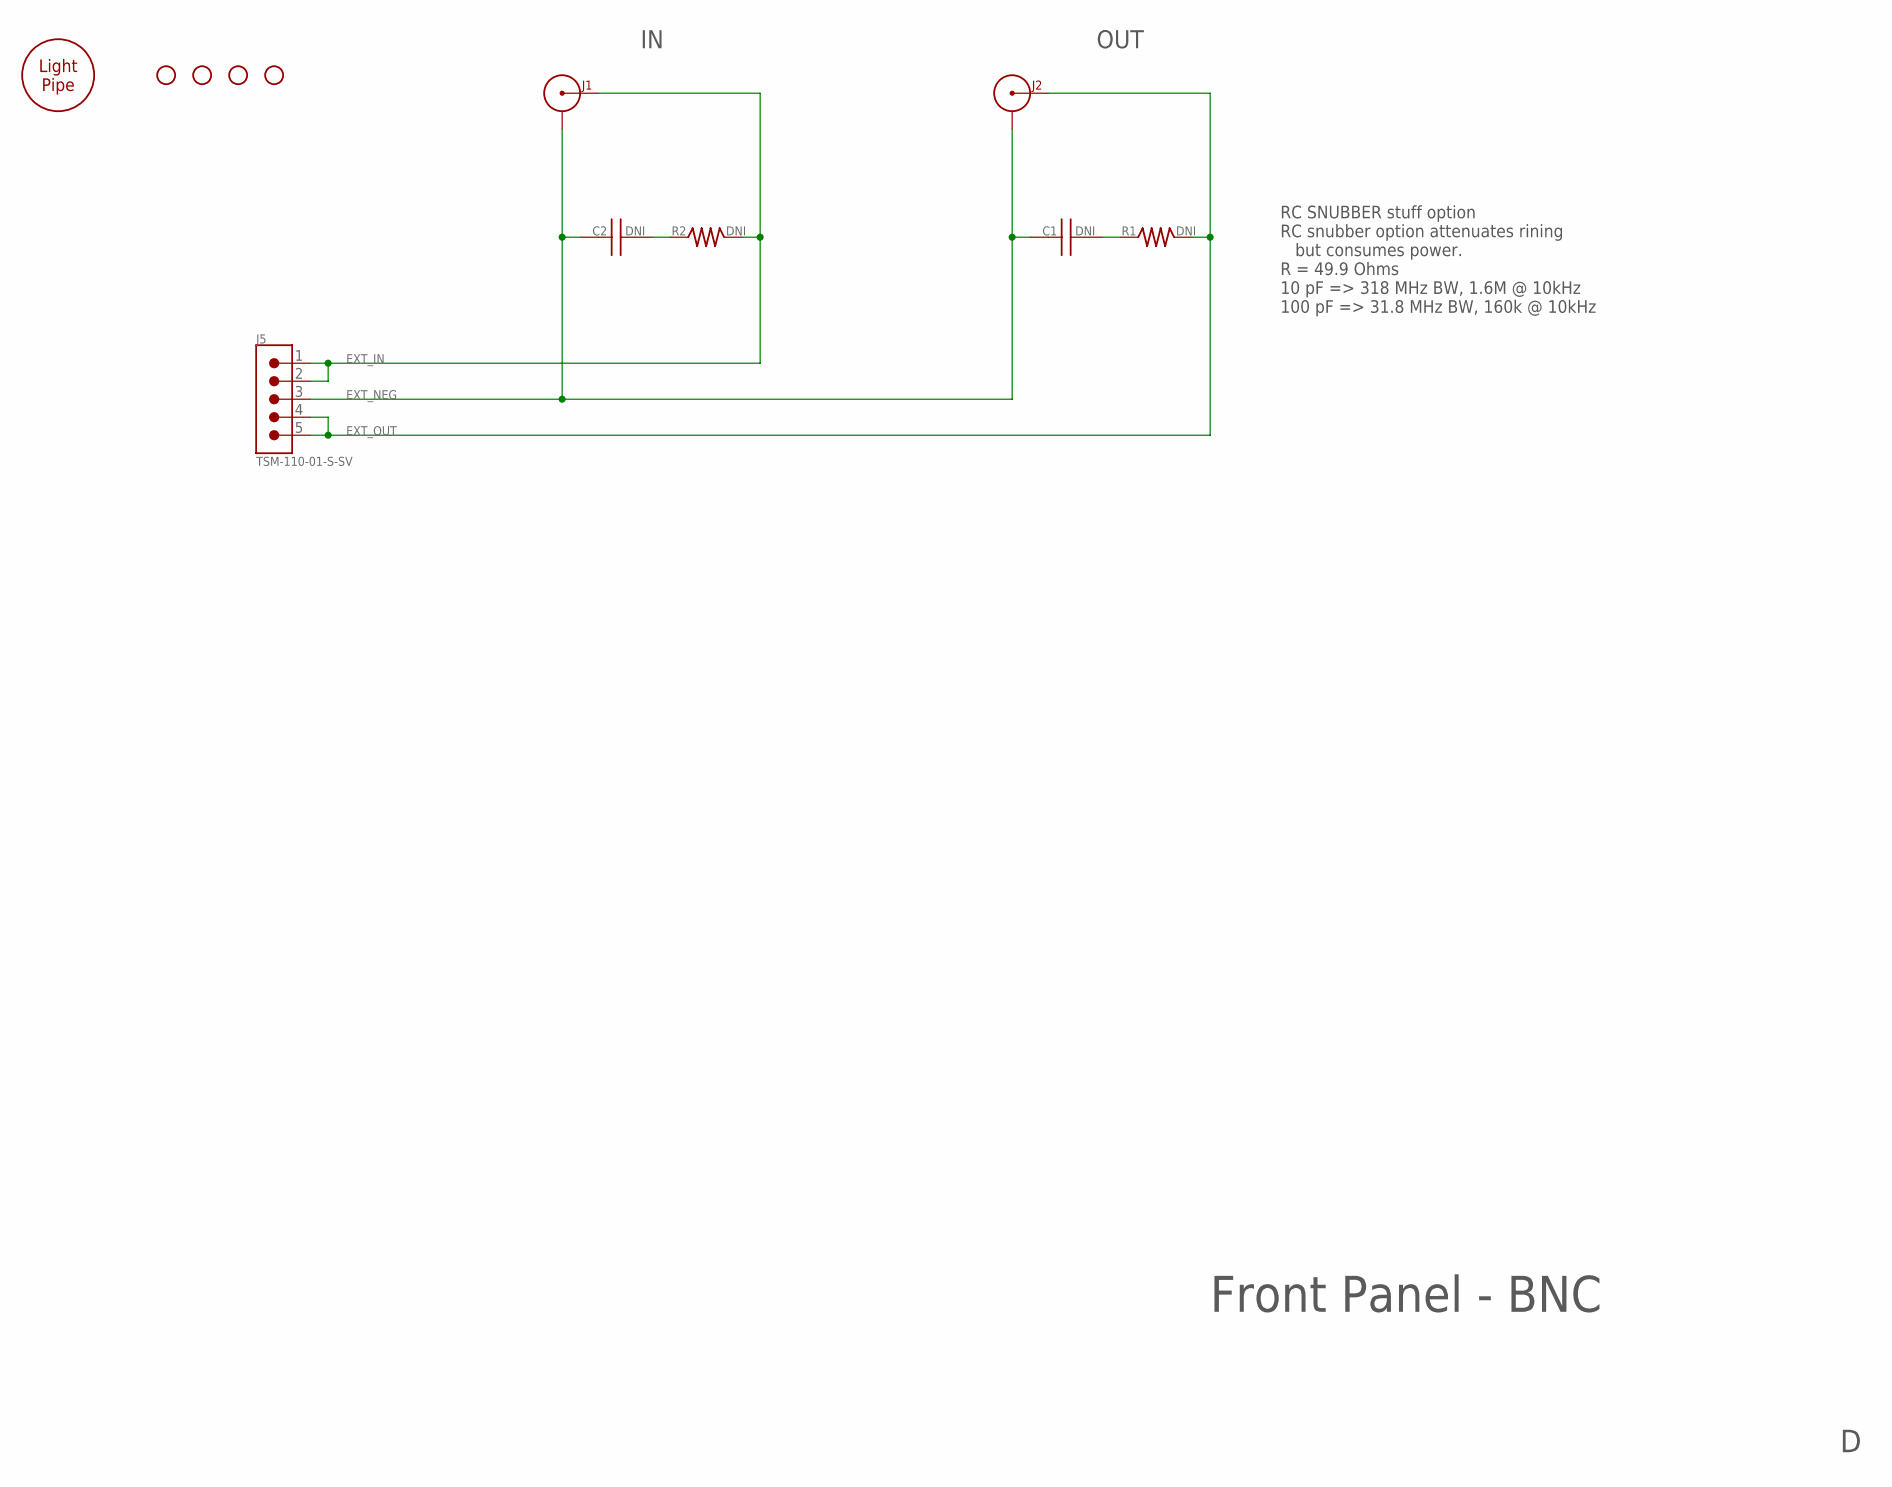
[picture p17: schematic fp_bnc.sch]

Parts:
C1, C2: DNI; 0603
H1: 51513020125F; LP_3MM; MPN 51513020125F
H2, H3, H4, H5: HOLE_#6; HOLE_3.5MM
J1, J2: 031-5329-52RFX; BNC_31-5329-52RFX; MPN 031-5329-52RFX
J5: TSM-110-01-S-SV; CONN_0.1_5X1_MS; MPN TSM-110-01-S-SV
R1, R2: DNI; 1206

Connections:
EXT_IN: J1.SIGNAL, J5.1, J5.2, R2.2
EXT_NEG: C1.1, C2.1, J1.G@1 (SHIELD), J1.G@2 (SHIELD), J1.G@3 (SHIELD), J1.G@4 (SHIELD), J2.G@1 (SHIELD), J2.G@2 (SHIELD), J2.G@3 (SHIELD), J2.G@4 (SHIELD), J5.3
EXT_OUT: J2.SIGNAL, J5.4, J5.5, R1.2
unnamed: C2.2, R2.1
unnamed: C1.2, R1.1

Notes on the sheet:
Front Panel - BNC
OUT
RC SNUBBER stuff option RC snubber option attenuates rining but consumes power. R = 49.9 Ohms 10 pF => 318 MHz BW, 1.6M @ 10kHz 100 pF => 31.8 MHz BW, 160k @ 10kHz

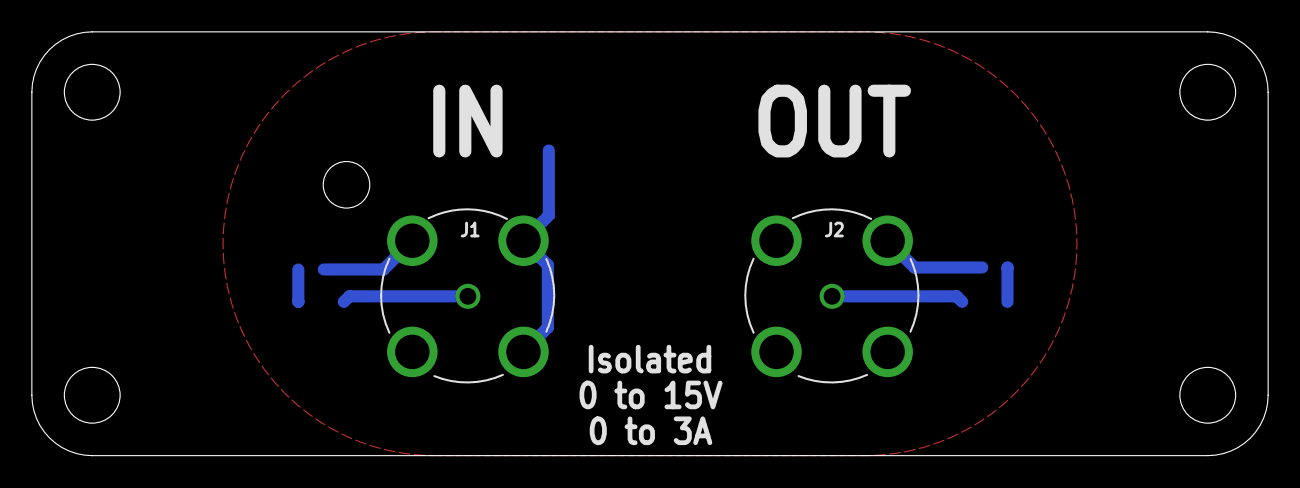
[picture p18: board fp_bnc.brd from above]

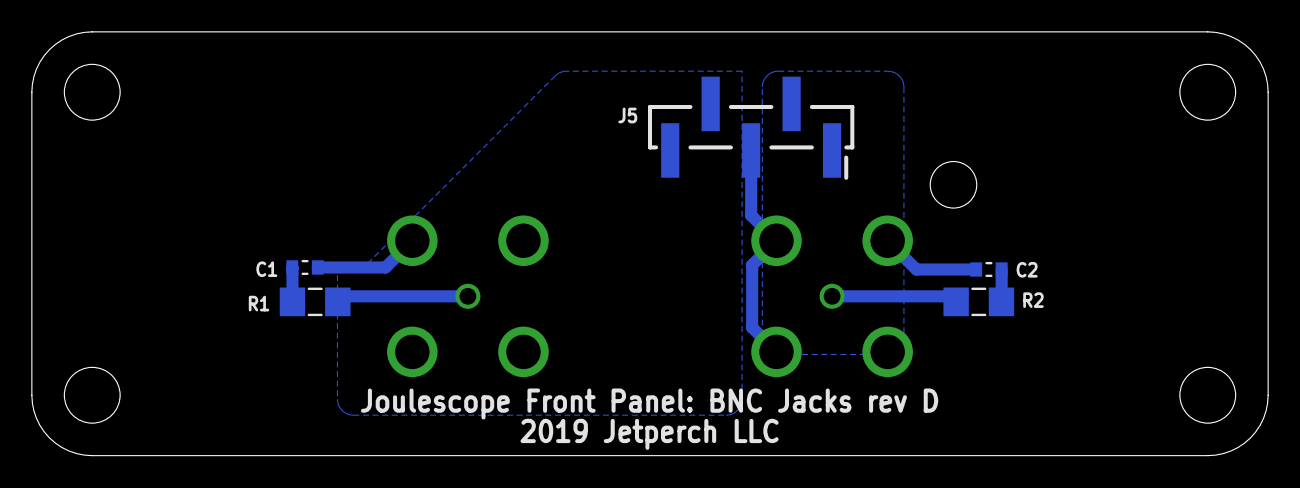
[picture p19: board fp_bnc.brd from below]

Board: 2 copper layers, 77.6 x 26.6 mm, 12 parts (5 on the bottom side), 5 nets.

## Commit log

2019-01-25 Initial public commit.
    [fp_banana.brd, fp_banana.sch, fp_baseline.brd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]
2019-03-19 Added binding posts front panel, updated baseline, and published baseline PDF.
    [fp_binding_posts.brd, fp_binding_posts.sch]
2019-03-20 Fixed backside keepout (in blue) so that it does not hide the rounded corners.
    [fp_baseline.brd]
2019-03-20 Clarified that blue is the backside keepout.
    [fp_baseline.brd]
2019-04-16 Pre-production update.
    * Increased clearances from chassis/enclosure ground.
    * Improved text.
    * Added gerbers.
    * Added USB back panel.
    [bp_led.sch, bp_usb.brd, fp_banana.brd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]
2019-04-16 Added PCBWay order notes to readme.
2019-04-16 Updated fp_baseline edit date.
    [fp_baseline.brd]
2019-05-09 Modified USB back panel to move GPI/O cutout and fixed schematic file name.
    [bp_usb.brd, bp_usb.sch]
2019-07-30 Updated baseline to clarify dimensions, placement and part numbers.
    [fp_baseline.brd, fp_baseline.sch]
2019-07-30 Added BOMs.
    [fp_banana_bom_revG.xlsx, fp_binding_posts_bom_revB.xlsx, fp_bnc_bom_revD.xlsx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]
2019-07-30 Added PDFs for fp_usb schematic and layout.
2019-08-12 Updated baseline front panel design.
    * Added gerbers
    * Added BOM
    * Added "Rev B" text to brd file.
    [fp_baseline.brd, fp_baseline_bom_revB.xlsx]
2019-08-13 Initial Kicad baseline front panel files commit
    [fp_baseline-B_CrtYd.gbr, fp_baseline-B_Cu.gbr, fp_baseline-B_Fab.gbr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]
2019-08-13 Fixed eagle/fp_usb mounting hole location which was off by 0.18 mm (7 mil).
    [fp_usb.brd, fp_usb.sch]
2019-08-13 Ignore KiCAD backup and cache files and removed from pull request.
2019-09-15 Added brief fab notes to back panel PCB design.
    [bp_usb.brd, bp_usb.sch]
2019-09-15 Banana Jack front panel rev H
    * Increased 5x1 connector pad width from 45 mil to 50 mil.
    * Added brief fab notes & fab drawing.
    * Improved dimensioning for clarity.
    * Removed excessive number of EXT_NEG vias.
    [fp_banana.brd, fp_banana.sch]
2019-10-21 Fixed binding post centerline offset dimension.
    [fp_binding_posts.brd]
2020-07-07 Added fp_usb3 gerber design. Thank you Mettler-Toledo AutoChem!
    [JouleScope USB 3.0 BOM.xlsx, PIK.csv]
